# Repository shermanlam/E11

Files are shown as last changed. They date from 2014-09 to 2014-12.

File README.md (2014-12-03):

E11
===

##Contact
Sherman Lam
slam@g.hmc.edu / shermanator94@yahoo.com
(626)383-1787

##Overview
This repository is used for storing any data for HMC's E11 course. It is primarily used for keeping track of the the beacon boards used for the competition playing field. The beacons are all designed using Eagle. Included in this repository is a library for custom components.

##Beacon Boards 

###V2

Second generation beacon boards and features uniformity between all types of beacons. All boards have the same code and hardware. This board was used in the 2014 Fall E11 course.

####Features
- All boards are capable of being bumped or flashed to. 
- 1 switch to select between bonus beacon mode vs normal mode
- 1 switch to select between flash vs bump modes
- SPI broken out
- All LEDs on transistor circuits

####Known Issues
- Gold-Code-flashing LEDs are spaced too far apart. Deadband when too close
- Push buttons work but are hard to push and can only be pushed from certain angles
- Current limiting resistors have debatable values. Adjust as needed.
- Gold code flashing LEDs need a current limiting resister per LED. Can't share
- LEDs currently powered off VDD (whatever comes in). Change to regulated 5V
- Board is slightly too long and jams on the playing field.

###V3

Third generation board that uses the 2nd generation board's general layout but fixes the known issues. This board has not been produced.

####Features
- Uses the omron tactile switches (B3F-4050).
- Additional switch to select between starting color.

####Known Issues / TODO
- Change switch for starting color to 3 pos? (green, white, unclaimed).

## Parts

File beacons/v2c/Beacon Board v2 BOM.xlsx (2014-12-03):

Beacon Board v2 Bill of Materials
Item | # of Boards | Quantity/Board | Total # | $ / Unit | Subtotal | Supplier | Link
Atmega 328 | 12 | 1 | 12 | 5.50 | 66.00 | Sparkfun | https://www.sparkfun.com/products/10524
28 Pin Socket (Atmega) | 12 | 1 | 12 | 0.399 | 4.79 | Digikey | http://www.digikey.com/product-detail/en/A28-LC-7-TT-R/AE10286-ND/1628669
16MHz Crystal | 12 | 1 | 12 | 0.323 | 3.88 | Digikey | http://www.digikey.com/product-search/en?KeyWords=631-1108-ND&WT.z_header=search_go
0.1uF cap | 12 | 2 | 24 | 0.246 | 5.90 | Digikey | http://www.digikey.com/product-detail/en/K104K10X7RF5UH5/BC2665CT-ND/2356879
0.47uF cap | 12 | 2 | 24 | 0.32 | 7.68 | Digikey | http://www.digikey.com/product-detail/en/EEU-EB1H470S/P13464-ND/949739
2pF cap | 12 | 1 | 12 | 0.43 | 5.16 | Digikey | http://www.digikey.com/product-detail/en/RCE5C1H2R0C0DBH03A/490-7366-1-ND/4277283
22 pF cap | 12 | 1 | 12 | 0.32 | 3.84 | Digikey | http://www.digikey.com/product-detail/en/K220J15C0GF5TL2/BC1005CT-ND/286627
Push Button | 12 | 2 | 24 | 1.071 | 25.70 | Digikey | http://www.digikey.com/product-detail/en/D6R10%20F1%20LFS/401-1973-ND/1466330
DIP Switches | 12 | 1 | 12 | 0.962 | 11.54 | Digikey | http://www.digikey.com/product-detail/en/76SB04T/GH7170-ND/726228
RED 5mm High Flux LED | 12 | 2 | 24 | 0.25 | 6.00 | SuperBrightLeds | https://www.superbrightleds.com/moreinfo/through-hole/5mm-red-high-flux-led-90-degree-viewing-angle-5500-mcd/356/1303/
Phototransistor | 12 | 1 | 12 | 2.875 | 34.50 | Digikey | http://www.digikey.com/product-search/en?x=0&y=0&lang=en&site=us&keywords=751-1020-ND
White 8mm LEDs | 12 | 1 | 12 | 1.89 | 22.68 | SuperBrightLeds | https://www.superbrightleds.com/moreinfo/through-hole/8mm-white-led-360-degree-viewing-angle-11000-millilumens/342/1289/
Red 8mm LEDs | 12 | 1 | 12 | 0.79 | 9.48 | SuperBrightLeds | https://www.superbrightleds.com/moreinfo/through-hole/8mm-red-led-360-degree-viewing-angle-2500-millilumens/347/1294/
Green 8mm LEDs | 12 | 1 | 12 | 1.49 | 17.88 | SuperBrightLeds | https://www.superbrightleds.com/moreinfo/through-hole/8mm-green-led-360-degree-viewing-angle-5000-millilumens/345/1292/
2N3904 | 12 | 4 | 48 | 0.173 | 8.30 | Digikey | http://www.digikey.com/product-detail/en/2N3904BU/2N3904FS-ND/1413
Total |  |  |  |  | 233.34

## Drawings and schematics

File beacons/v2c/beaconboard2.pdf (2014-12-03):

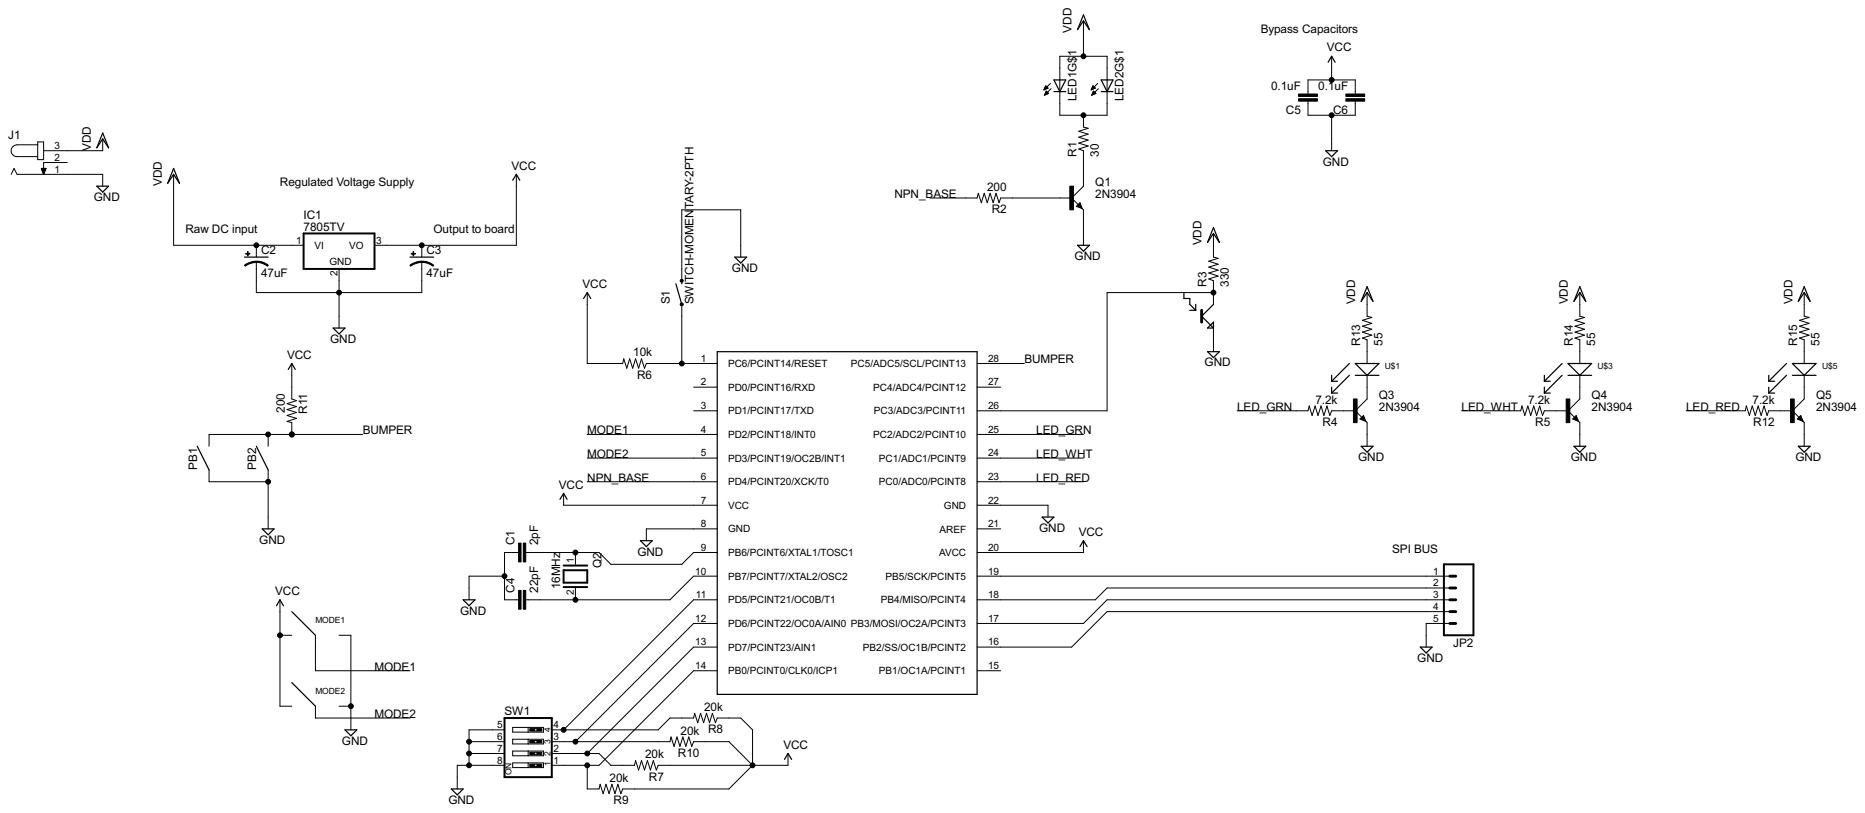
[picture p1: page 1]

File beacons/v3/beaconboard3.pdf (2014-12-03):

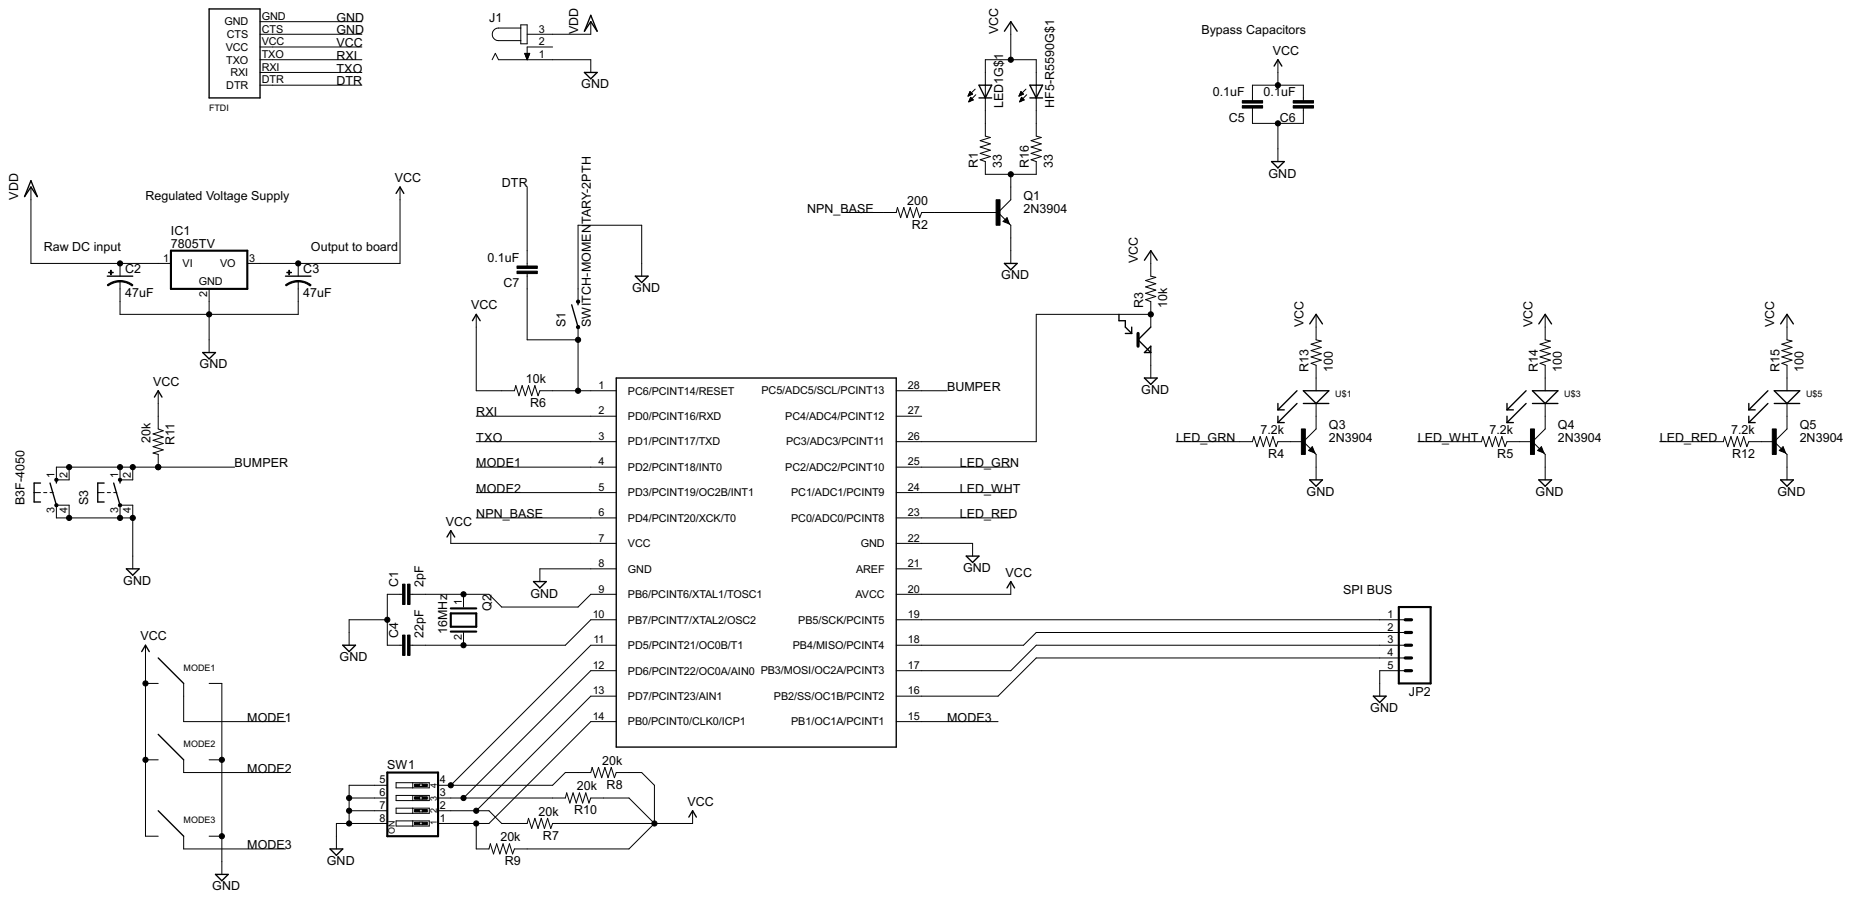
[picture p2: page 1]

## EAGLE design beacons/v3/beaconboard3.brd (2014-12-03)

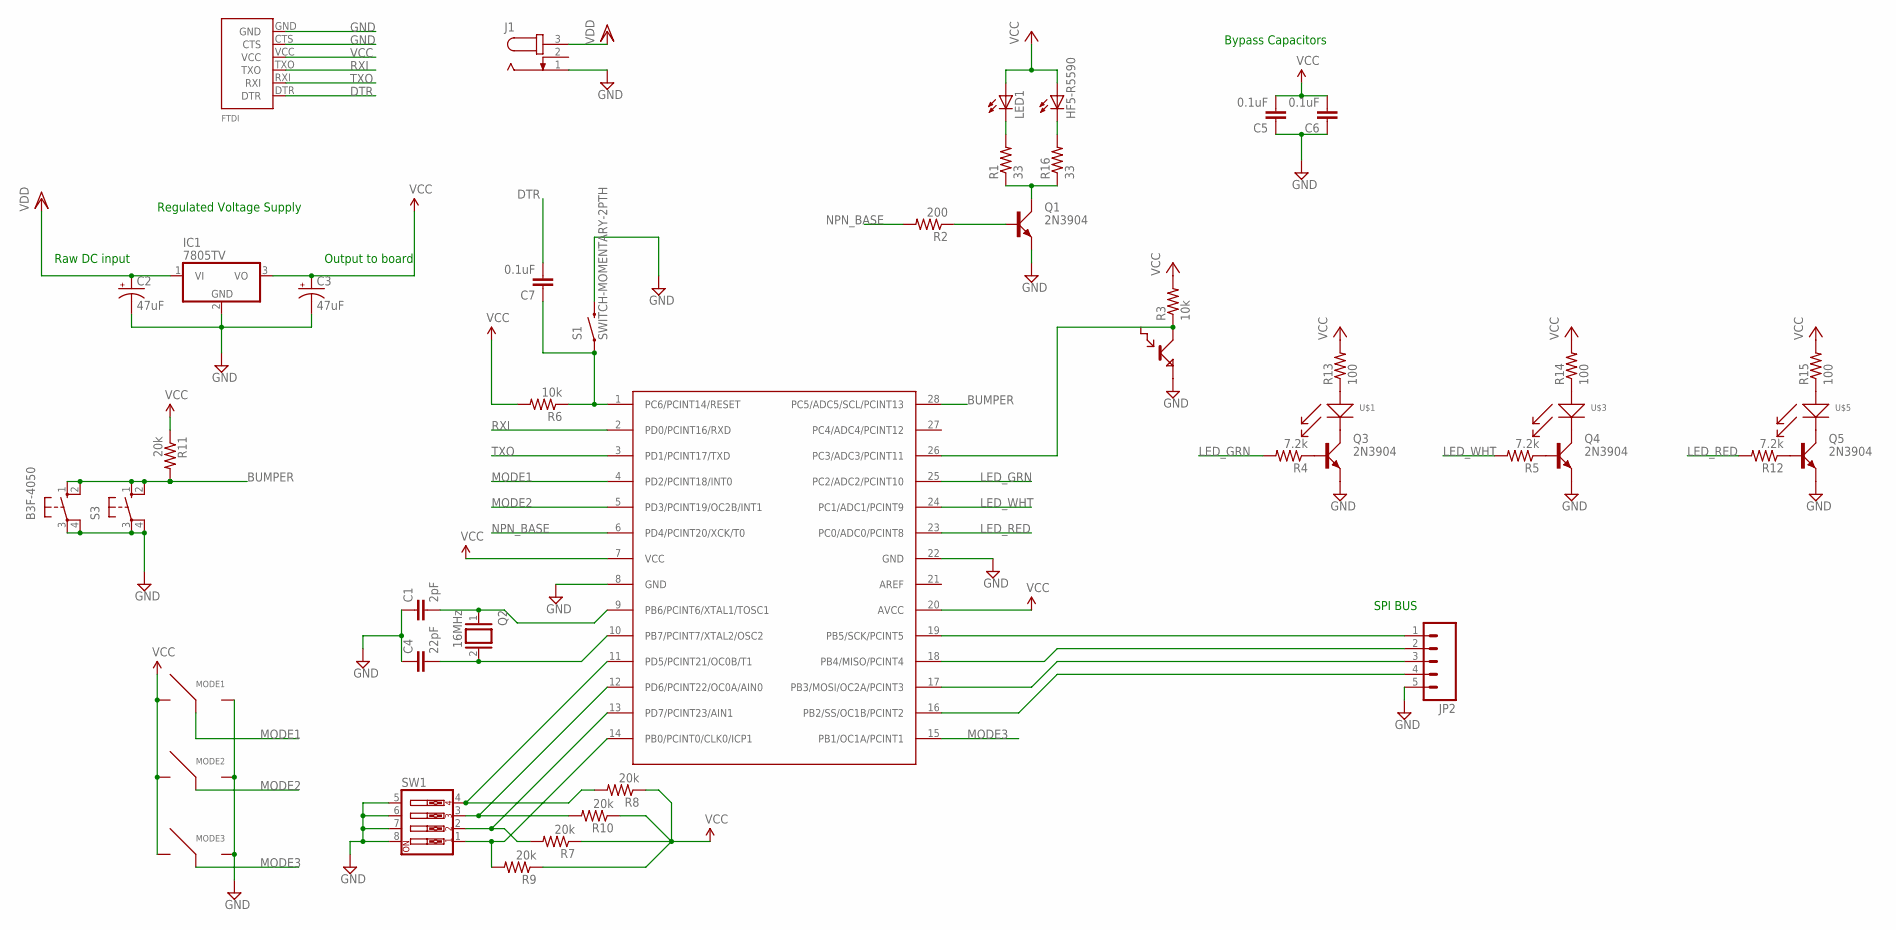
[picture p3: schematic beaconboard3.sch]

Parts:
B3F-4050: 40-XX; B3F-40XX
C1: 2pF; CAP-PTH-SMALL
C2, C3: 47uF; CPOL-RADIAL-10UF-25V
C4: 22pF; CAP-PTH-SMALL
C5, C6, C7: 0.1uF; CAP-PTH-5MM
HF5-R5590: LED-2AC-CP41B-WES; CP41B
IC1: 7805TV; TO220V
J1: JACK-PLUG1; SPC4078
JP2: M05LOCK_LONGPADS; 1X05_LOCK_LONGPADS
LED1: LED-2AC-CP41B-WES; CP41B
MODE1, MODE2, MODE3: SPD_SLIDE_SWITCH; SPDT_SLIDE_SWITCH
Q1, Q3, Q4, Q5: 2N3904; TO92D
Q2: 16MHz; QS
R1, R16: 33; AXIAL-0.4
R2: 200; AXIAL-0.4
R3, R6: 10k; AXIAL-0.4
R4, R5, R12: 7.2k; AXIAL-0.4
R7, R8, R9, R10, R11: 20k; AXIAL-0.4
R13, R14, R15: 100; AXIAL-0.4
S1: SWITCH-MOMENTARY-2PTH; TACTILE-PTH
S3: 40-XX; B3F-40XX
SW1: SW_DIP-4; EDG-04
U$1, U$3, U$5: 8MM_LED
U$2: BPW77NA; TO-18
U$4: ATMEGA328; DIL28-3
U$6: FTDI

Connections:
BUMPER: B3F-4050.1 (S), B3F-4050.2 (S1), R11.P$2 (2), S3.1 (S), S3.2 (S1), U$4.28 (PC5/ADC5/SCL/PCINT13)
DTR: C7.2, U$6.DTR
GND: B3F-4050.3, B3F-4050.4 (P1), C1.1, C2.2 (-), C3.2 (-), C4.1, C5.1, C6.1, IC1.2 (GND), J1.1, JP2.5, MODE1.3, MODE2.3, MODE3.3, Q1.E, Q3.E, Q4.E, Q5.E, S1.3 (2), S3.3, S3.4 (P1), SW1.5, SW1.6, SW1.7, SW1.8, U$2.E, U$4.8 (GND), U$4.22 (GND), U$6.CTS, U$6.GND
LED_GRN: R4.P$2 (2), U$4.25 (PC2/ADC2/PCINT10)
LED_RED: R12.P$2 (2), U$4.23 (PC0/ADC0/PCINT8)
LED_WHT: R5.P$2 (2), U$4.24 (PC1/ADC1/PCINT9)
MODE1: MODE1.2, U$4.4 (PD2/PCINT18/INT0)
MODE2: MODE2.2, U$4.5 (PD3/PCINT19/OC2B/INT1)
MODE3: MODE3.2, U$4.15 (PB1/OC1A/PCINT1)
unnamed: Q1.C, R1.P$1 (1), R16.P$1 (1)
unnamed: Q1.B, R2.P$1 (1)
unnamed: LED1.1 (C), LED1.4 (C), R1.P$2 (2)
unnamed: Q3.B, R4.P$1 (1)
unnamed: JP2.1, U$4.19 (PB5/SCK/PCINT5)
unnamed: JP2.2, U$4.18 (PB4/MISO/PCINT4)
unnamed: JP2.3, U$4.17 (PB3/MOSI/OC2A/PCINT3)
unnamed: Q4.B, R5.P$1 (1)
unnamed: R3.P$1 (1), U$2.C, U$4.26 (PC3/ADC3/PCINT11)
unnamed: Q5.B, R12.P$1 (1)
unnamed: C7.1, R6.P$1 (1), S1.1, U$4.1 (PC6/PCINT14/RESET)
unnamed: C1.2, Q2.1, U$4.9 (PB6/PCINT6/XTAL1/TOSC1)
unnamed: C4.2, Q2.2, U$4.10 (PB7/PCINT7/XTAL2/OSC2)
unnamed: R7.P$2 (2), SW1.2, U$4.13 (PD7/PCINT23/AIN1)
unnamed: R8.P$2 (2), SW1.4, U$4.11 (PD5/PCINT21/OC0B/T1)
unnamed: R10.P$2 (2), SW1.3, U$4.12 (PD6/PCINT22/OC0A/AIN0)
unnamed: Q3.C, U$1.NEG
unnamed: Q4.C, U$3.NEG
unnamed: R9.P$2 (2), SW1.1, U$4.14 (PB0/PCINT0/CLK0/ICP1)
unnamed: JP2.4, U$4.16 (PB2/SS/OC1B/PCINT2)
unnamed: Q5.C, U$5.NEG
unnamed: R13.P$1 (1), U$1.POS
unnamed: R14.P$1 (1), U$3.POS
unnamed: R15.P$1 (1), U$5.POS
unnamed: HF5-R5590.1 (C), HF5-R5590.4 (C), R16.P$2 (2)
NPN_BASE: R2.P$2 (2), U$4.6 (PD4/PCINT20/XCK/T0)
RXI: U$4.2 (PD0/PCINT16/RXD), U$6.TXO
TXO: U$4.3 (PD1/PCINT17/TXD), U$6.RXI
VCC: C3.1 (+), C5.2, C6.2, HF5-R5590.2 (A), HF5-R5590.3 (A), IC1.3 (VO), LED1.2 (A), LED1.3 (A), MODE1.1, MODE2.1, MODE3.1, R3.P$2 (2), R6.P$2 (2), R7.P$1 (1), R8.P$1 (1), R9.P$1 (1), R10.P$1 (1), R11.P$1 (1), R13.P$2 (2), R14.P$2 (2), R15.P$2 (2), U$4.7 (VCC), U$4.20 (AVCC), U$6.VCC
VDD: C2.1 (+), IC1.1 (VI), J1.3

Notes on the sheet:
Output to board
Raw DC input
Bypass Capacitors
Regulated Voltage Supply
SPI BUS

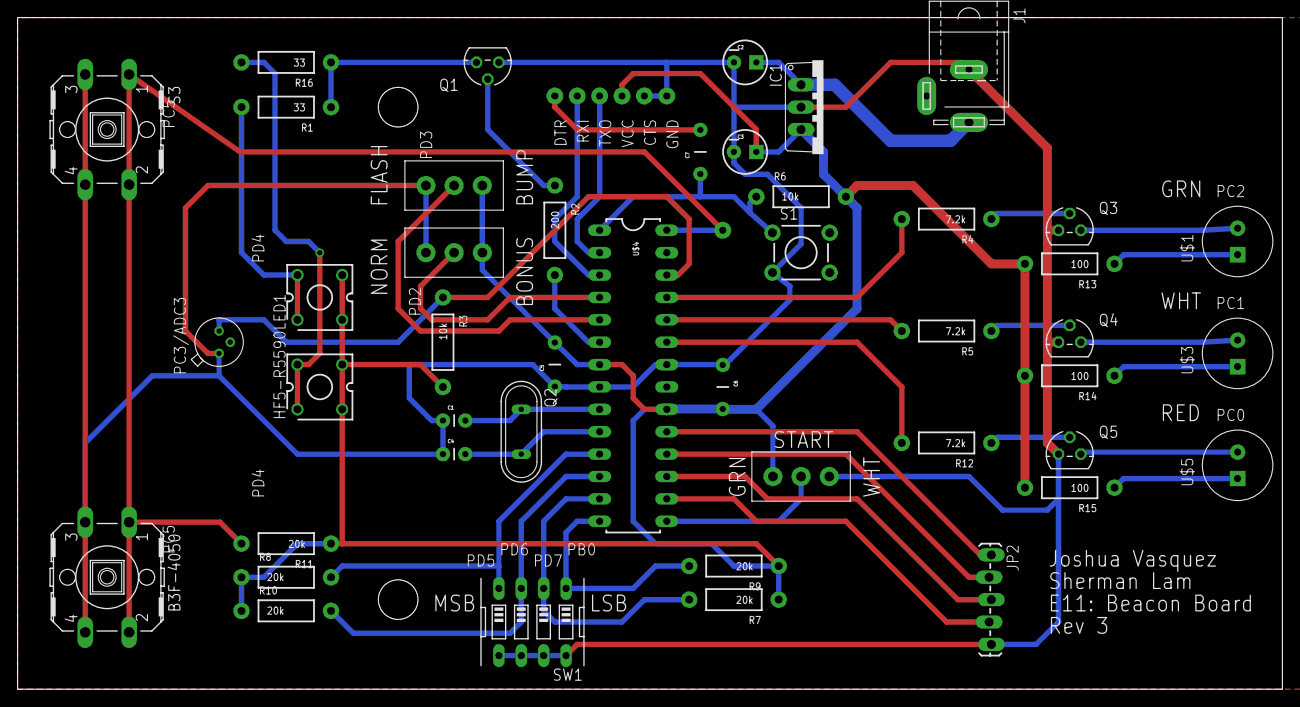
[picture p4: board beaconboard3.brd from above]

Board: 2 copper layers, 143.5 x 76.2 mm, 46 parts (0 on the bottom side), 39 nets.

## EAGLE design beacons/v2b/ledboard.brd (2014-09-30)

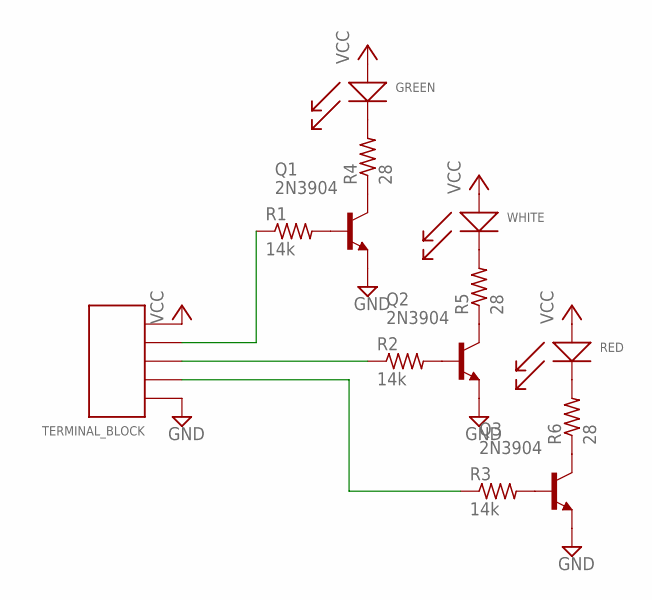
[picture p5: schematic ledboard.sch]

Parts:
GREEN: 8MM_LED
Q1, Q2, Q3: 2N3904; TO92
R1, R2, R3: 14k; 0207/12
R4, R5, R6: 28; 0207/12
RED: 8MM_LED
TERMINAL_BLOCK: 1X5_3.5MM_TERMINAL_BLOCK
WHITE: 8MM_LED

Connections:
GND: Q1.3 (E), Q2.3 (E), Q3.3 (E), TERMINAL_BLOCK.5
unnamed: Q1.2 (B), R1.2
unnamed: Q2.2 (B), R2.2
unnamed: Q3.2 (B), R3.2
unnamed: Q1.1 (C), R4.1
unnamed: Q2.1 (C), R5.1
unnamed: Q3.1 (C), R6.1
unnamed: GREEN.NEG, R4.2
unnamed: R5.2, WHITE.NEG
unnamed: R6.2, RED.NEG
unnamed: R1.1, TERMINAL_BLOCK.2
unnamed: R2.1, TERMINAL_BLOCK.3
unnamed: R3.1, TERMINAL_BLOCK.4
VCC: GREEN.POS, RED.POS, TERMINAL_BLOCK.1, WHITE.POS

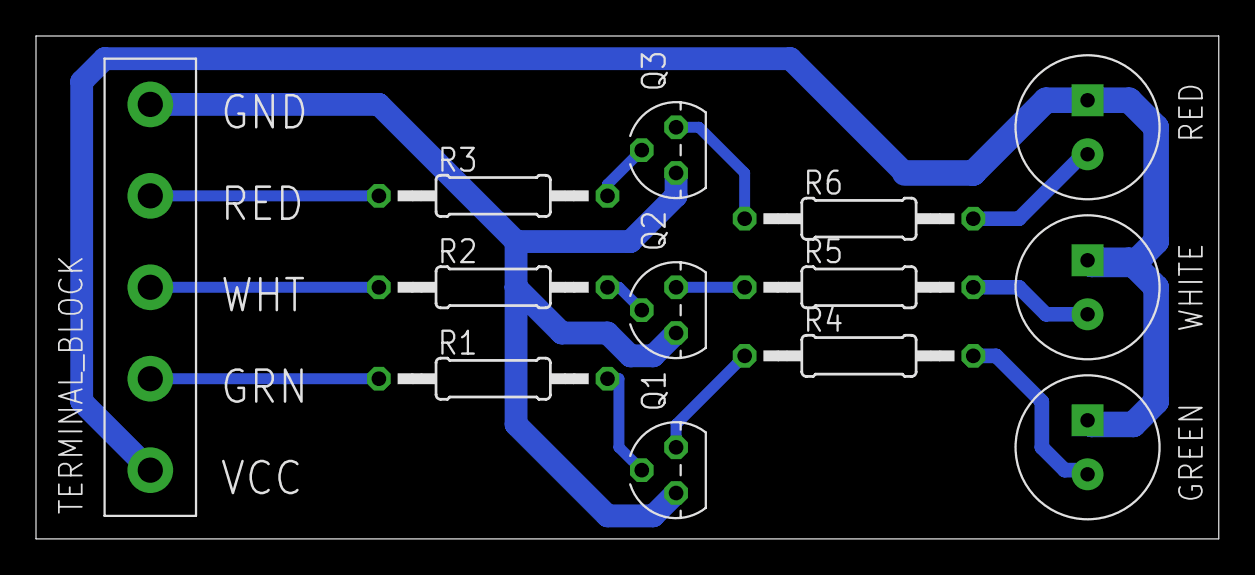
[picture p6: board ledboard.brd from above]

Board: 2 copper layers, 65.7 x 27.9 mm, 13 parts (0 on the bottom side), 14 nets.

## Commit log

2014-09-23 Added E11 board
    [beaconboard.brd, beaconboard.sch]
2014-09-27 Added LED breakout board and e11 eagle library
    [beaconboard2.brd, beaconboard2.sch, ledboard.brd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]
2014-09-28 Added phototransistor
    [beaconboard2.brd, beaconboard2.sch, ledboard.brd]
2014-09-30 Added switches for mode control
    [BOM.xlsx, beaconboard2.brd, beaconboard2.sch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]
2014-10-09 Added beaconboard 3, extended version
    [beaconboard2.brd, beaconboard3.brd, beaconboard3.sch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]
2014-11-05 Updated beaconboard with staff suggestions
    [beaconboard3.brd, beaconboard3.sch]
2014-11-21 Restructured the directory
    [BOM.xlsx, beaconboard.brd, beaconboard.sch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]
2014-11-21 Restructure directory
    [BOM.xlsx, beaconboard.brd, beaconboard.sch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]
2014-12-03 Updated readme. Added omron switches in version 3
    [beaconboard3.brd, beaconboard3.sch]
2014-12-03 Added pdf of sch and updated boms
    [Beacon Board v2 BOM.xlsx, Beacon Board v3 BOM.xlsx, beaconboard3.brd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]

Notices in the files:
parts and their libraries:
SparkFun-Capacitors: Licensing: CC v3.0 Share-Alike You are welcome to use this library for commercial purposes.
